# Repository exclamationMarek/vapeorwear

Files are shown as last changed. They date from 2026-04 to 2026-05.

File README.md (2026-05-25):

# VAPEorWEAR
Wearable SAO power pack

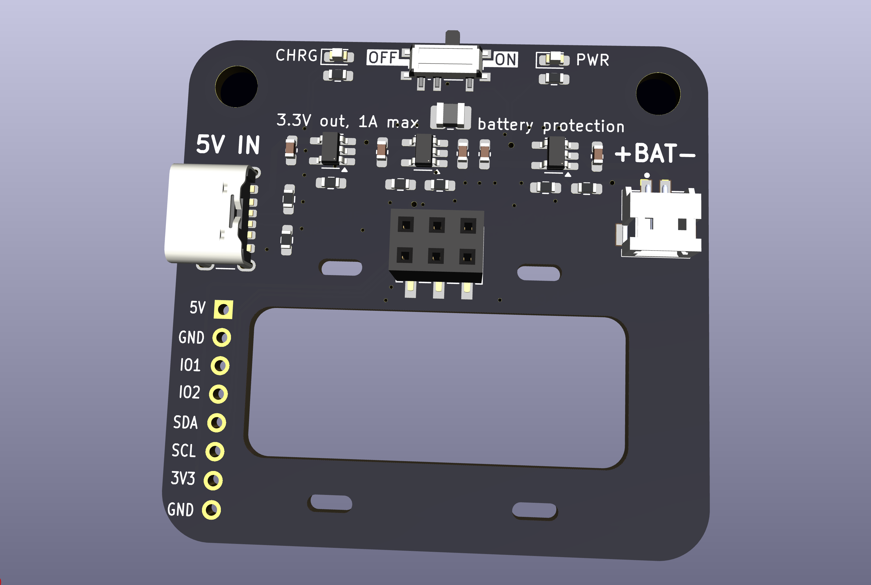
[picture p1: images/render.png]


Designed around a battery, that is upcycled from a single use vape, that a friend of mine found (in worryingly large quantities) in the recycling room of his house. It features a proper battery charger and protection IC, so that the poor, abused lithium cell can now live a comfortable afterlife powering your shitty add ons!

# Features
* 400mAh upcycled battery that might smell like fruity vape juice
* Regulated 3.3V output, 1A max, with short circuit protection
* 2x M4 holes that should fit lanyard clips
* Rounded edges and no poking-out THT pins on the backside, to not ruin your nice t-shirt
* Battery protection and charging from USB
* On-Off switch (with a <3µA shutdown current)

# Kit content
If you received a kit, it should contain:
* 1x PCB
* 1x Up-cycled battery. It may smell fruity and be a bit sticky. I attempted to wash it.
* 3x Different ICs in SOT-23. Don't confuse which one is which!
* 1x USB connector
* 1x sliding switch
* 1x battery connector
* 1x SAO connector
* 1x 4.7uH inductor in 1008 package
* 1x 21k resistor
* 2x 1uF capacitor
* 3x 10uF capacitor
* 4x 560ohm resistor
* 5x 4.7k resistor

# Assembly instruction
For your convenience, most components are arranged in simple rows. The recommended order of soldering is row by row, and each row is listed **from left to right**

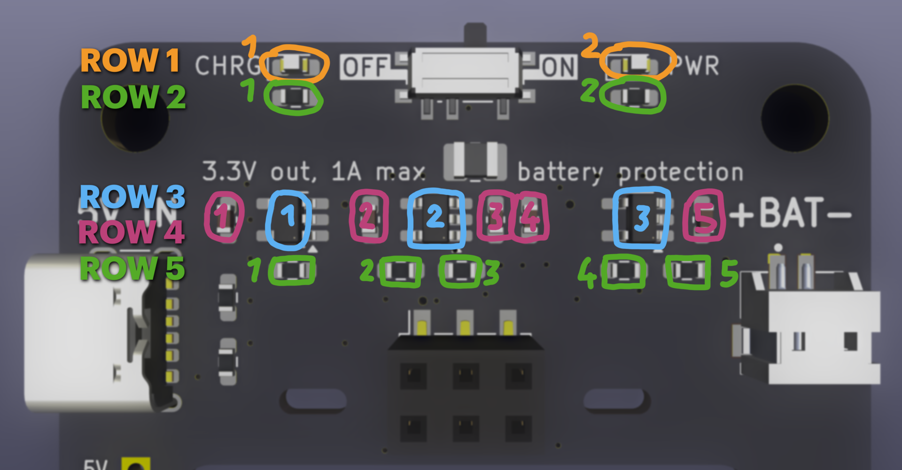
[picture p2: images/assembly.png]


## ROW 1: LEDS
Negative (stripe) always faces left
1. White LED (charging indicator)
2. White LED (power indicator)

## ROW 2: LED resistors
1. 560R (sets brightness of charging LED)
2. 560R (sets brightness of power LED)
You can swap them for 4.7k ones if you want the LEDs dimmer

## ROW 3: ICs
Pin 1 (dot) is always bottom right
1. BRCL4054CME (battery charger). Package marking: "4054C"
2. MT3406 (buck converter). Package marking: "A1xx" (example: A15a)
3. RY2201 (battery protection). Package marking: "MKxxx" (example: MKJ3L)

## ROW 4: Capacitors
1. 1uF (bypass for charger)
2. 10uF (bypass for buck)
3. 10uF (output for buck)
4. 10uF (more output for buck, optional)
5. 1uF (bypass for protection IC)

## ROW 5: Resistors
1. 4.7k (charge current set resistor. 4.7k->212mA, 2k->500mA, 10k->100mA)
2. 4.7k (VOUT set resistor LOW)
3. 21k	(VOUT set resistor HIGH. Included combination results in 3.24V out)
4. 4.7k	(Buck converter ENABLE pull-up). Can be pretty much any value.
5. 560R	(Battery protection IC power filter)

## Remaining components:
Their position and orientation has been left as an exercise to the assembler
1. 4.7uH inductor for the buck converter
2. On-off switch
3. Battery connector
4. USB-C port
5. 2x 4.7k resistors near the USB-C port (yeah I know these are supposed to be 5.1k but I din't have those on a spool so this is what you get in the kit. Since it's a 1% one, It's stil in the 10% tollerance allowed for the 5.1k by the USB spec so as blasmphemous as this is, it should work)
6. SAO connector. Unkeyed, sorry!

# Post assembly test
1. Do not plug in battery yet!
2. Plug in USB power source and test if VBAT reads approx. 4.2V
	* The charge LED is allowed to blink erratically
3. Turn the switch ON and check if 3.3V out reads approx 3.3V 
4. Check polarity of battery cable. Compare it with the print on the silkscreen
5. If so, you can unplug the usb, plug in the battery and enjoy your VAPEorWEAR

# Design details
## [RY2201](https://www.lcsc.com/datasheet/C370889.pdf) battery protection IC
* Overcharge protection at 4.3V
* Overdischarge protection at 2.4V
* Overcurrent protection at 3.0A

## [BRCL4054CME](https://www.lcsc.com/datasheet/C305436.pdf) battery charger IC
* CCCV charging to 4.2V
* R11 sets charging current. Recommended 4.99k gives 200mA (2.5h charge time)
* For fastest allowed charging (500mA) use 2k resistor instead. 
* CHRG led will shine during charging, and gently glow when done

## [MT3406](https://www.lcsc.com/datasheet/C22462728.pdf) buck converter
* Efficiently produces 3.3V from VBAT
* 1A output continuous, 2A self-protected limit
* Paired with [INPAQ WIP252012P-4R7ML](https://www.lcsc.com/datasheet/C964123.pdf) inductor (4.7µH, 1.9A ISat, 196mΩ)
* Not a boost-buck, so output voltage will start dropping as VBAT drops below 3.4V

## [ON/OFF switch](https://www.lcsc.com/datasheet/C22435662.pdf) and PWR LED
* Switch controls the ENABLE pin of the buck converter
* LED is connected to the output 3.3V rail
* Quiescent current when OFF < 3µA
* Quiescent current when ON approx. 1.2mA, mostly due to the power LED

## [USB-C port](https://www.lcsc.com/datasheet/C42400650.pdf) for 5V input

## 31 x 13mm battery cavity
* With 4x 3x1.5mm zip-tie or tape slots for mounting
* Prominently shows the battery, no mechanical cell protection offered
* JST-ZH (1.5mm) 2-pin connector

## 2.54mm pin row for connecting to the SAO
* breaks out all SAO pins, and 5V and extra GND
* VCC, GND and I2C pins are arranged so that an I2C OLED (example SSD1306) can be connected directly, should the SAO feature a micro and wish to display something.

# Other notes
The component values are a bit funky, since they are heavily consolidated for making convinient kits. If you are assembling this with access to a full selection of passives, pick better values. The KiCad design files contain more recommended values.

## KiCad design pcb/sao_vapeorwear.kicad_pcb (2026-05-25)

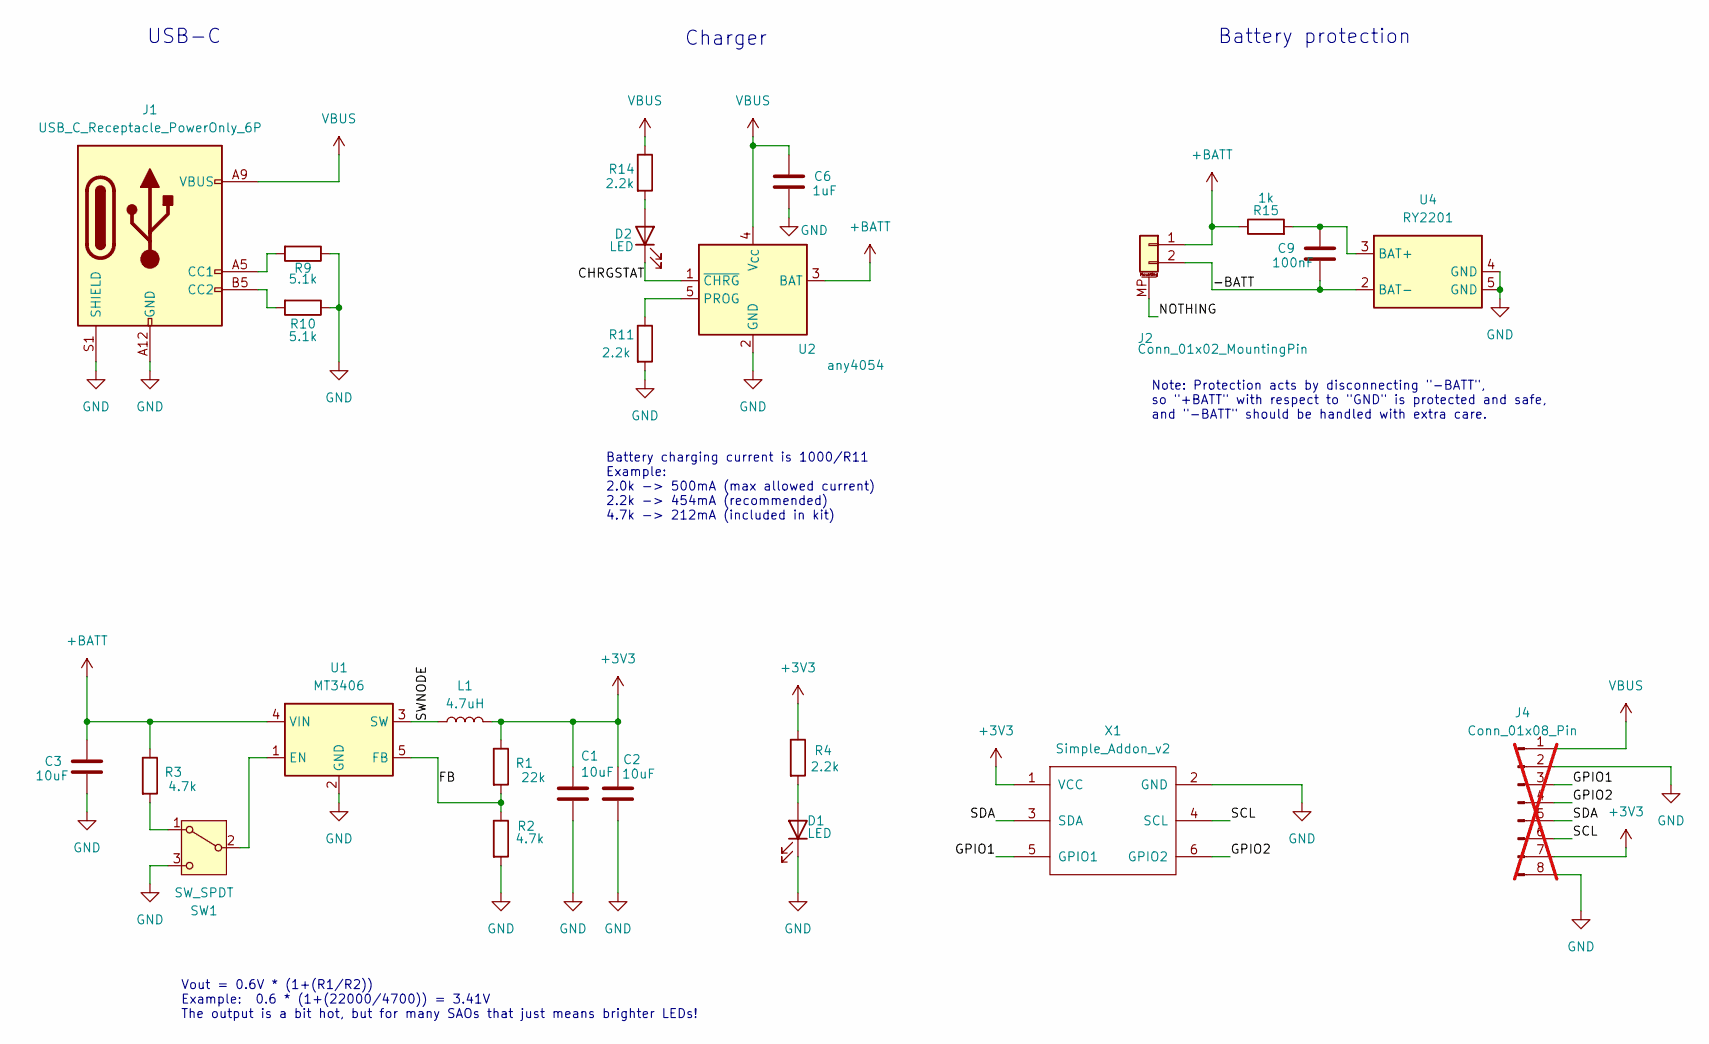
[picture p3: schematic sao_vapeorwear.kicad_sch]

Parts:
C1, C2, C3: 10uF; C_0603_1608Metric_Pad1.08x0.95mm_HandSolder
C6: 1uF; C_0603_1608Metric_Pad1.08x0.95mm_HandSolder
C9: 100nF; C_0603_1608Metric_Pad1.08x0.95mm_HandSolder
D1, D2: LED; LED_0603_1608Metric_Pad1.05x0.95mm_HandSolder
J1: USB_C_Receptacle_PowerOnly_6P; USB_C_Receptacle_GCT_USB4125-xx-x-0190_6P_TopMnt_Horizontal
J2: Conn_01x02_MountingPin; JST_ZH_S2B_1x02_HORIZONTAL
J4: Conn_01x08_Pin; PinHeader_1x08_P2.54mm_Vertical; not fitted
L1: 4.7uH; L_1008_2520Metric_Pad1.43x2.20mm_HandSolder
R1: 22k; R_0603_1608Metric_Pad0.98x0.95mm_HandSolder
R2, R3: 4.7k; R_0603_1608Metric_Pad0.98x0.95mm_HandSolder
R4, R11, R14: 2.2k; R_0603_1608Metric_Pad0.98x0.95mm_HandSolder
R9, R10: 5.1k; R_0603_1608Metric_Pad0.98x0.95mm_HandSolder
R15: 1k; R_0603_1608Metric_Pad0.98x0.95mm_HandSolder
SW1: SW_SPDT; SW_SPDT_PCM12
U1: MT3406; SOT-23-5_HandSoldering
U2: any4054; SOT-23-5_HandSoldering
U4: RY2201; SOT-23-5_HandSoldering
X1: Simple_Addon_v2; PinSocket_2x03_P2.54mm_Vertical_SMD

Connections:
+3V3: C1.1, C2.1, J4.7, L1.2, R1.1, R4.1, X1.1 (VCC)
+BATT: C3.1, J2.1, R3.1, R15.1, U1.4 (VIN), U2.3 (BAT)
/-BATT: C9.2, J2.2, U4.2 (BAT-)
/CHRGSTAT: D2.1 (K), U2.1 (~CHRG)
/FB: R1.2, R2.1, U1.5 (FB)
/GPIO1: J4.3, X1.5 (GPIO1)
/GPIO2: J4.4, X1.6 (GPIO2)
/NOTHING: J2.MP (MountPin)
/SCL: J4.6, X1.4 (SCL)
/SDA: J4.5, X1.3 (SDA)
/SWNODE: L1.1, U1.3 (SW)
GND: C1.2, C2.2, C3.2, C6.2, D1.1 (K), J1.A12 (GND), J1.B12 (GND), J1.S1 (SHIELD), J4.2, J4.8, R2.2, R9.1, R10.1, R11.2, SW1.3 (C), U1.2 (GND), U2.2 (GND), U4.4 (GND), U4.5 (GND), X1.2 (GND)
unnamed: D1.2 (A), R4.2
unnamed: D2.2 (A), R14.2
unnamed: J1.A5 (CC1), R9.2
unnamed: J1.B5 (CC2), R10.2
unnamed: R3.2, SW1.1 (A)
unnamed: SW1.2 (B), U1.1 (EN)
unnamed: R11.1, U2.5 (PROG)
unnamed: C9.1, R15.2, U4.3 (BAT+)
VBUS: C6.1, J1.A9 (VBUS), J1.B9 (VBUS), J4.1, R14.1, U2.4 (V_{CC})

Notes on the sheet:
Charger
Battery protection
Vout = 0.6V * (1+(R1/R2)) Example: 0.6 * (1+(22000/4700)) = 3.41V The output is a bit hot, but for many SAOs that just means brighter LEDs!
Battery charging current is 1000/R11 Example: 2.0k -> 500mA (max allowed current) 2.2k -> 454mA (recommended) 4.7k -> 212mA (included in kit)
USB-C
Note: Protection acts by disconnecting "-BATT", so "+BATT" with respect to "GND" is protected and safe, and "-BATT" should be handled with extra care.

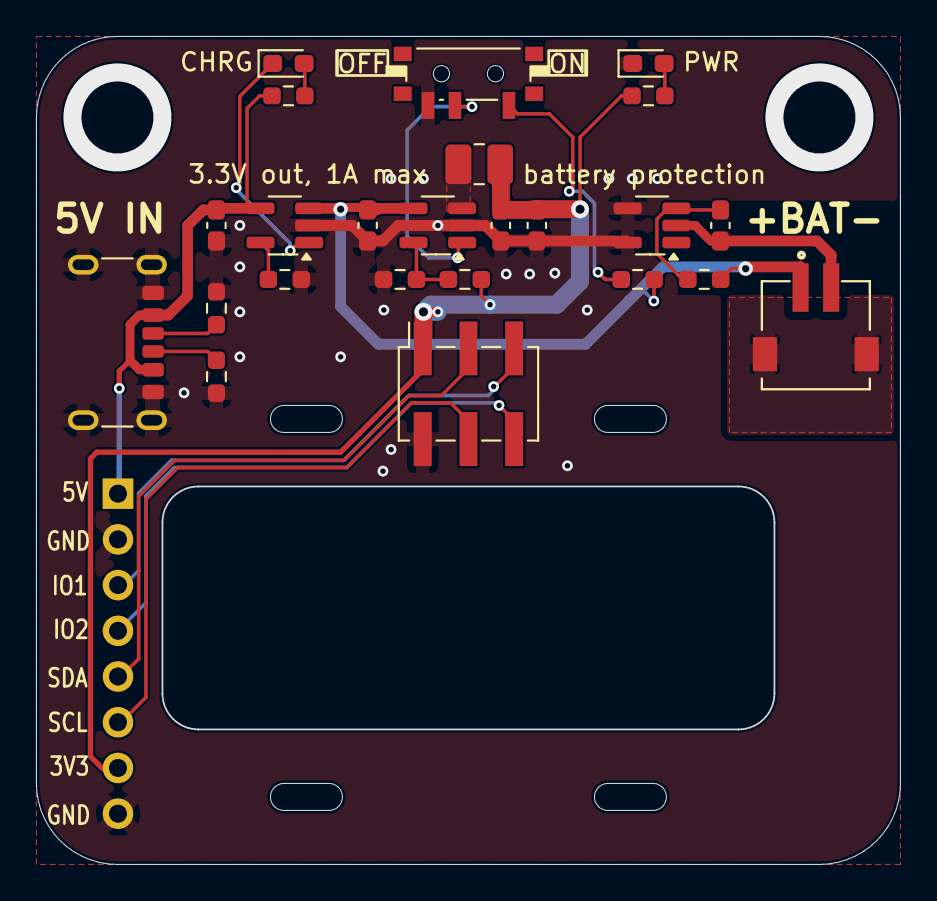
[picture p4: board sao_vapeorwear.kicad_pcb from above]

Board: 2 copper layers, 48.0 x 46.0 mm, 25 parts (0 on the bottom side), 20 nets.

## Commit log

2026-04-29 made the documentation a bit more tldr resistant
2026-05-17 Better documentation
    [sao_vapeorwear.kicad_pcb, sao_vapeorwear.kicad_sch]
2026-05-25 component values
    [sao_vapeorwear.kicad_pcb, sao_vapeorwear.kicad_sch]
